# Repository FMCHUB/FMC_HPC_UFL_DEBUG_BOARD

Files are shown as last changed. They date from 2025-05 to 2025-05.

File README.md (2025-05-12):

# FMC HPC U.FL Debug Board

A flexible breakout and debugging platform for High-Pin Count (HPC) FPGA Mezzanine Cards (FMC).  
Provides 156 signal connections via U.FL connectors, plus SMA and clamp probing options for signal measurement and testing.

📄 [**View Online Datasheet**](https://fmchub.github.io/projects/FMC_HPC_UFL_DEBUG_BOARD/Datasheet/FMC_HPC_UFL_DEBUG_BOARD_datasheet.html)

---

## 🔧 Features

- FMC HPC (VITA 57.1) compatible connector
- 156 signals broken out to U.FL connectors
- 68 LA (LPC) + 48 HA (HPC) + 8 CLK + 16 MGT differential signals
- 8 SMA connectors for high-speed probing
- 8 clamp connectors for low-speed oscilloscope probing
- Breakout of power pins, JTAG, and I²C (solderable pin headers)
- Stackable mechanical assembly with standoff mounting holes
- Open-source hardware

---

## 📚 Documentation

| Resource | Link |
|---|---|
| Datasheet | [HTML Version](https://fmchub.github.io/projects/FMC_HPC_UFL_DEBUG_BOARD/Datasheet/FMC_HPC_UFL_DEBUG_BOARD_datasheet.html) |
| Schematics | `/Drawings/T0017_HPC_UFL_DEBUG_BOARD_SCHEMATICS_2024_12_13_REV_A.pdf` |
| PCB Layers | `/Drawings/T0017_HPC_UFL_DEBUG_BOARD_LAYERS_2024_12_13_REV_A.pdf` |
| Mechanical Drawings | `/Drawings/T0017_HPC_UFL_DEBUG_BOARD_MECHANICAL_2024_12_13_REV_A.pdf` |
| Bill of Materials | `/FMC_HPC_UFL_DEBUG_BOM.csv` |
| Buy online | [IAM Electronic Webshop](https://www.iamelectronic.com/shop) |

---

## 🛠️ Assembly & Usage Notes

- Board exceeds FMC single-width outline → check mechanical clearance in your setup.
- Use spacers or standoffs to prevent mechanical stress.
- For JTAG/I²C use, solder standard 2.54 mm pin headers to breakout pads.
- SMA and U.FL connectors are intended for signal probing. Ensure correct termination.

---

## ⚠️ Warnings

- **Incorrect loopback or interconnects can damage connected hardware**. Always verify voltage levels and signal directions before making U.FL cable connections.
- Clamp connectors are suitable for low-frequency probing only.

---

## 💡 Applications

- FMC-based FPGA system debugging
- Signal probing (low-speed and high-speed)
- Loopback and interconnect test setups
- Educational FPGA labs and research environments

---

## 📘 License

This project is licensed under the **Do What The Fuck You Want To Public License (WTFPL)**.

> See [`LICENSE`](./COPYING) for full text.

---

## ✉️ Contact

Feedback and contributions welcome via GitHub Issues or Pull Requests.

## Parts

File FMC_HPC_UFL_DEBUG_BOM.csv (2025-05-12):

Designator | Comment | Manufacturer | Part | Quantity
J1, J2, J3, J4, J5, J6, J7, J8, J9, J10, J11, J12, J13, J14, J15, J16, J17, J18, J19, J20, J21, J22, J23, J24, J25, J26, J27, J28, J29, J30, J31, J32, J33, J34, J35, J36, J37, J38, J39, J40, J41, J42, J43, J44, J45, J46, J47, J48, J49, J50, J51, J52, J53, J54, J55, J56, J57, J58, J59, J60, J61, J62, J63, J64, J65, J66, J67, J68, J69, J70, J71, J72, J73, J74, J75, J76, J77, J78, J79, J80, J81, J82, J83, J84, J85, J86, J87, J88, J89, J90, J91, J92, J93, J94, J95, J96, J97, J98, J99, J100, J101, J102, J103, J104, J105, J106, J107, J108, J109, J110, J111, J112, J113, J114, J115, J116, J117, J118, J119, J120, J121, J122, J123, J124, J125, J126, J127, J128, J129, J130, J131, J132, J133, J134, J135, J136, J137, J138, J139, J140, J141, J142, J143, J144, J145, J146, J147, J148, J149, J150, J151, J152, J153, J154, J155, J156, JA1, JB1, JC1, JD1, JE1, JF1, JG1, JH1 | U.FL-R-SMT-1(01) | Hirose Electric | U.FL-R-SMT-1(01) | 164
TPA1, TPB1, TPC1, TPD1, TPE1, TPF1, TPG2, TPH1 | Testpoint | Keystone Electronics | 5095 | 8
JA2, JB2, JC2, JD2, JE2, JF2, JG2, JH2 | SMA-J-P-H-ST-EM1 | Samtec | SMA-J-P-H-ST-EM1 | 8
P1 | MC-HPC-10 | Samtec | ASP-134488-01 | 1
P2 | CC-HPC-10 | Samtec | ASP-134486-01 | 1

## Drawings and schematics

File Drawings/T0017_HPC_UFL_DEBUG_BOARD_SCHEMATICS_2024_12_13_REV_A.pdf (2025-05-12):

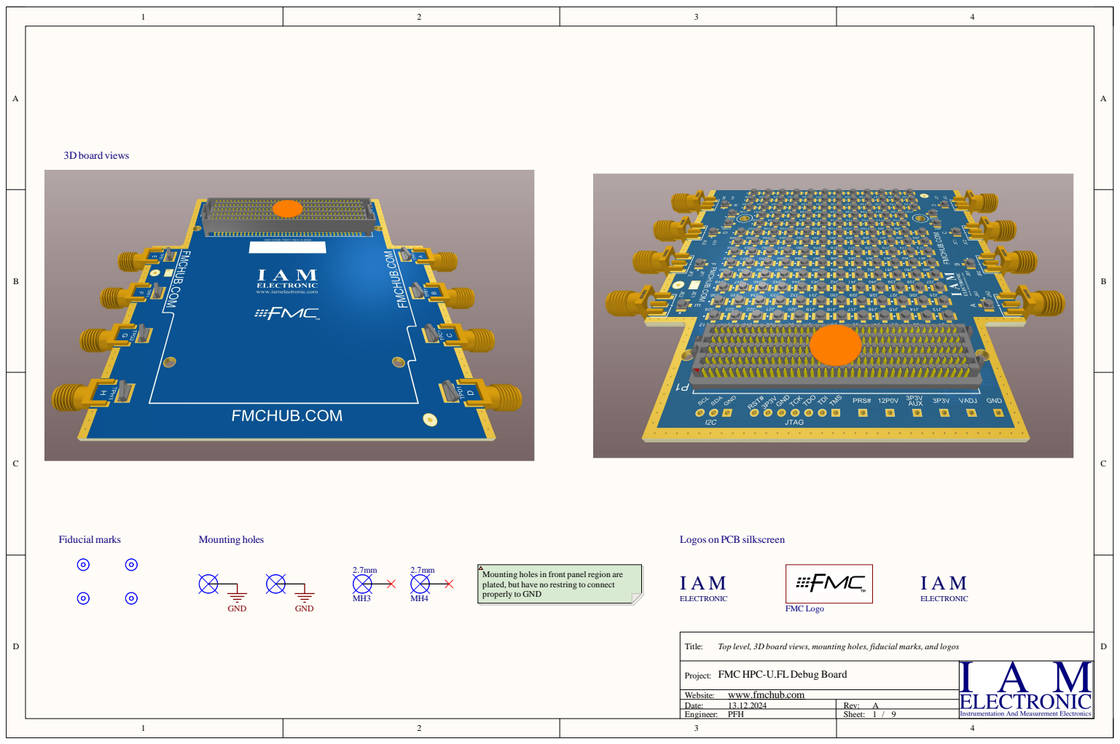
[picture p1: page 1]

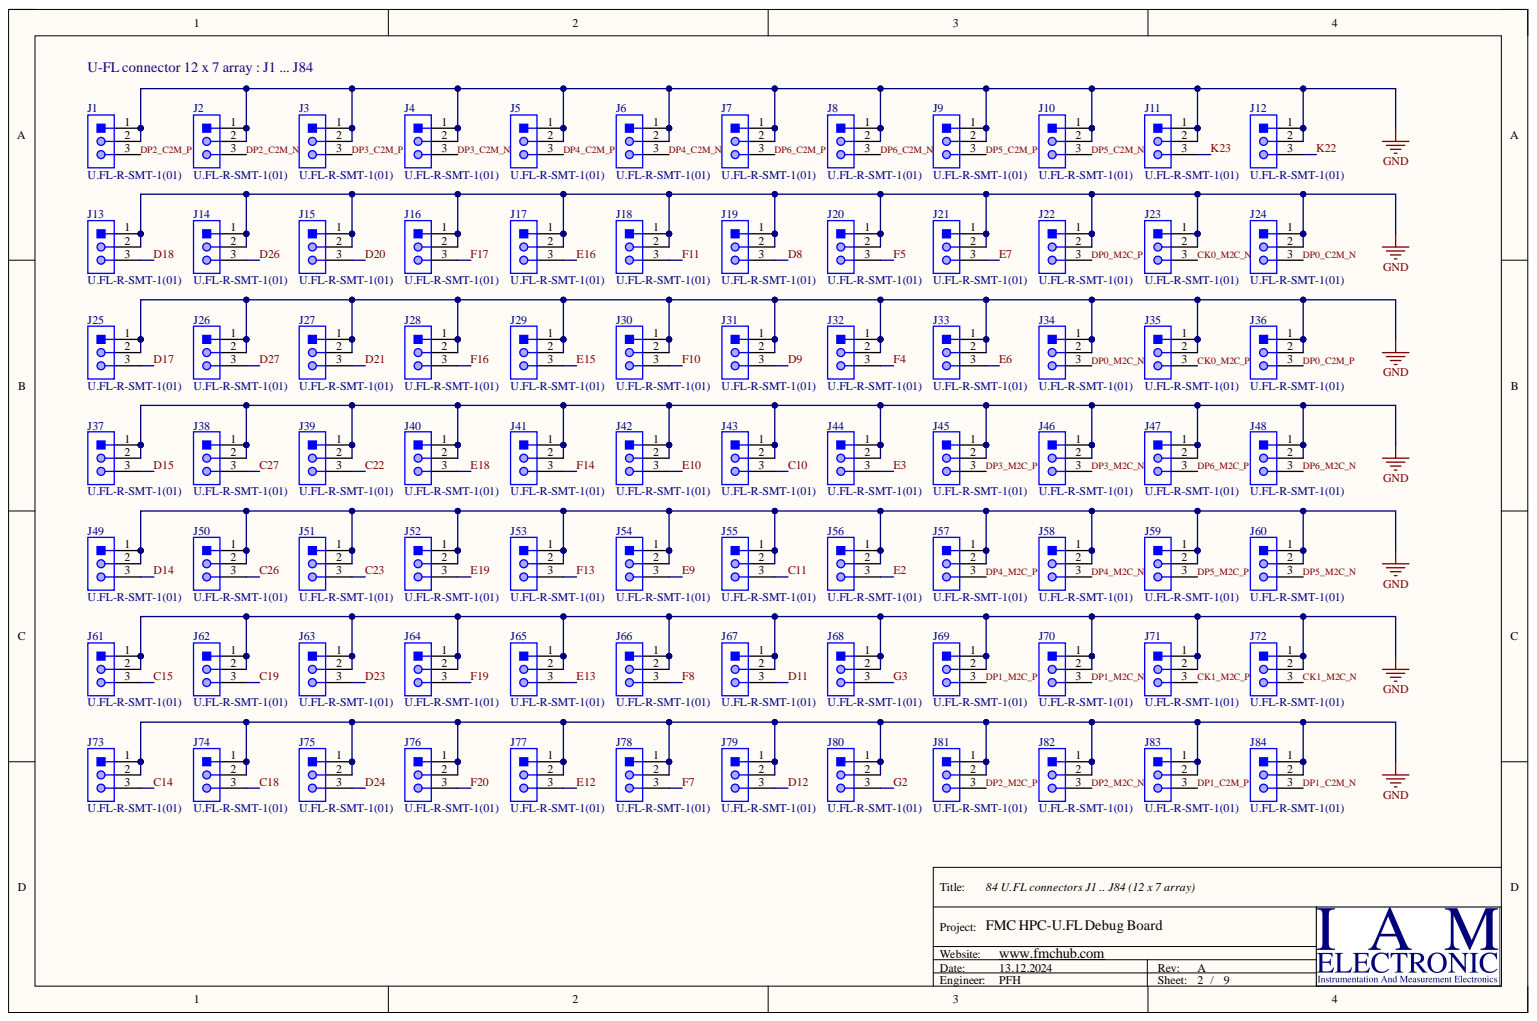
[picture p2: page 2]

FMC HPC-U.FL Debug Board

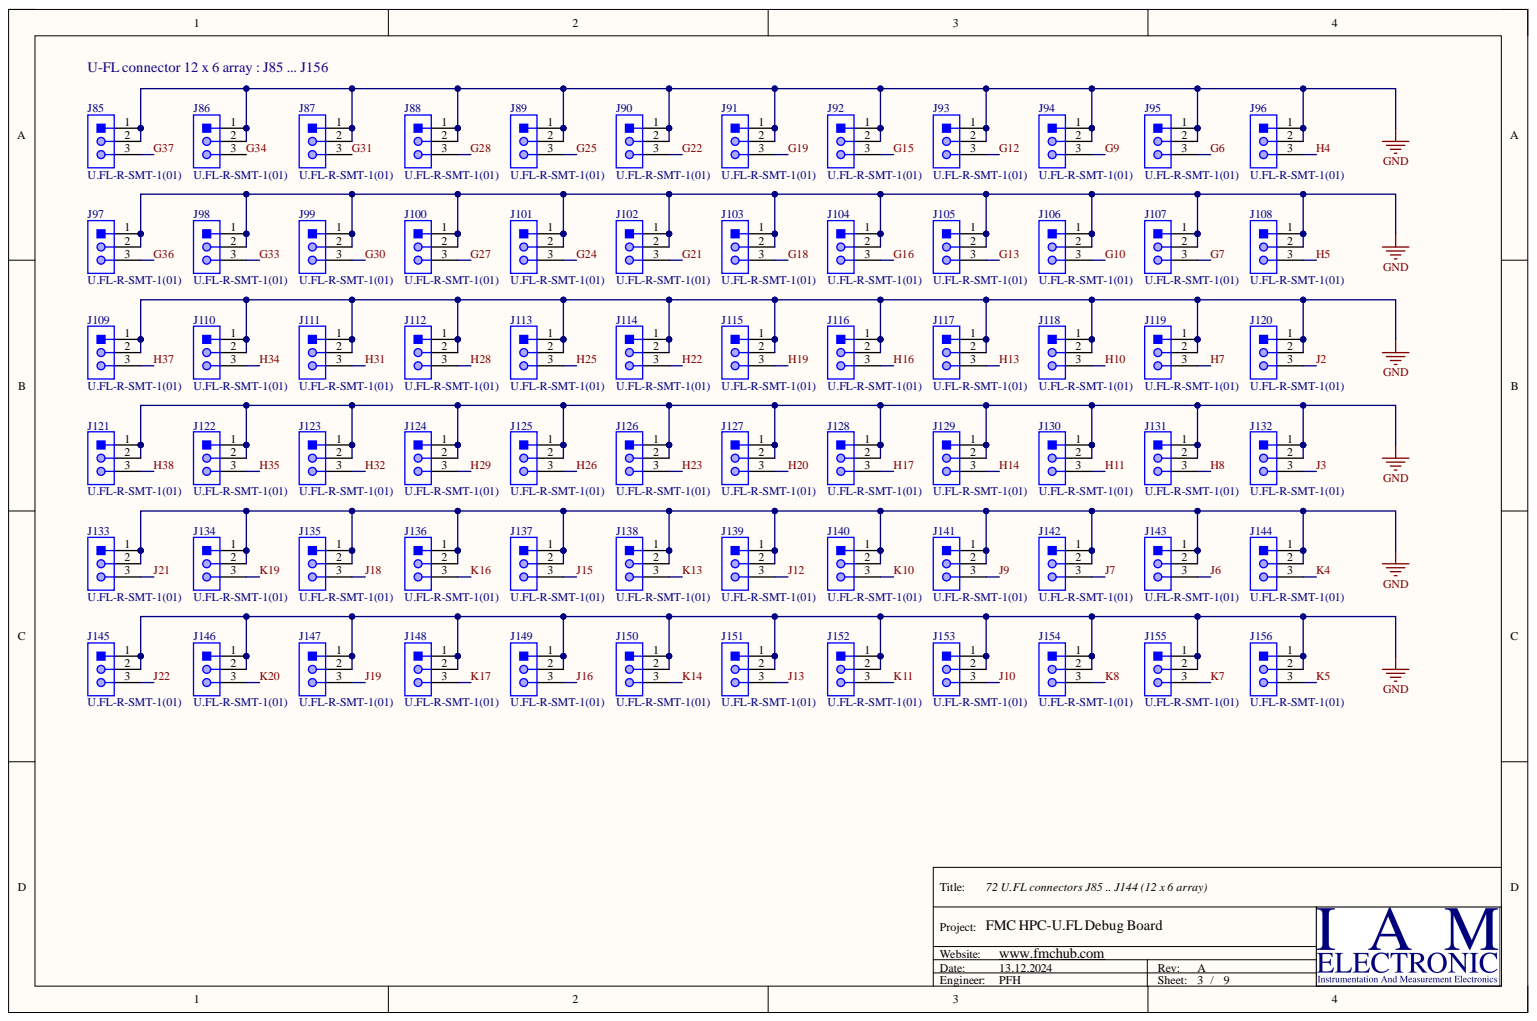
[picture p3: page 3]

FMC HPC-U.FL Debug Board

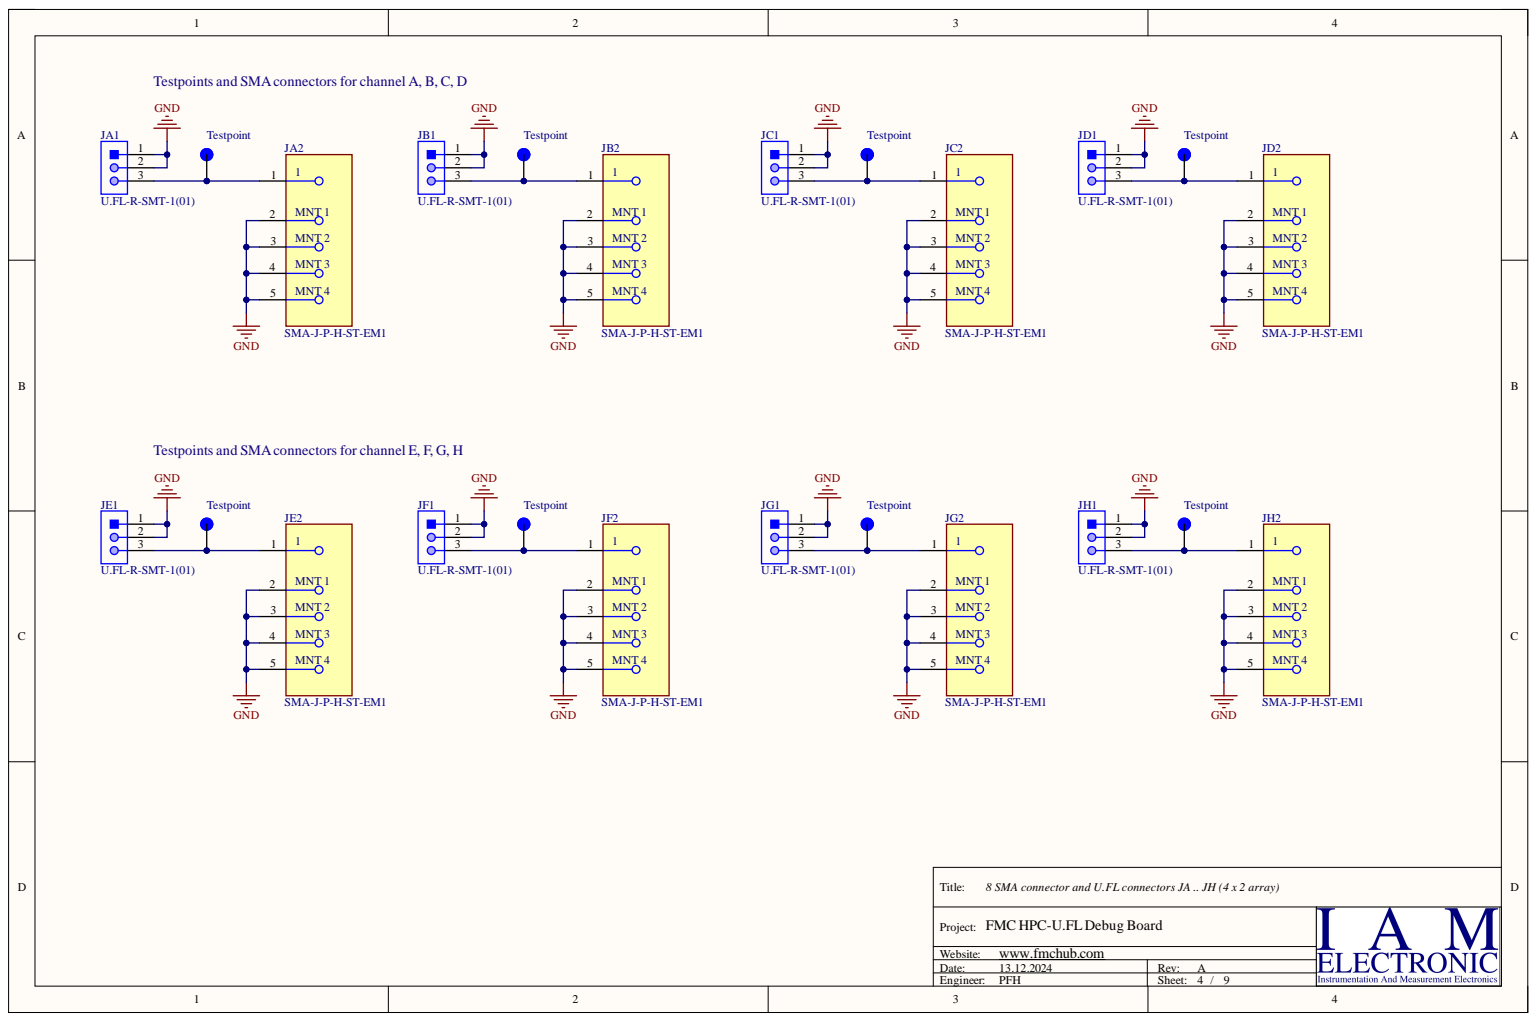
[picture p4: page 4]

Testpoints and SMAconnectors for channel A, B, C, D

Testpoints and SMAconnectors for channel E, F, G, H

8 SMA connector and U.FL connectors JA .. JH (4 x 2 array)

FMC HPC-U.FL Debug Board

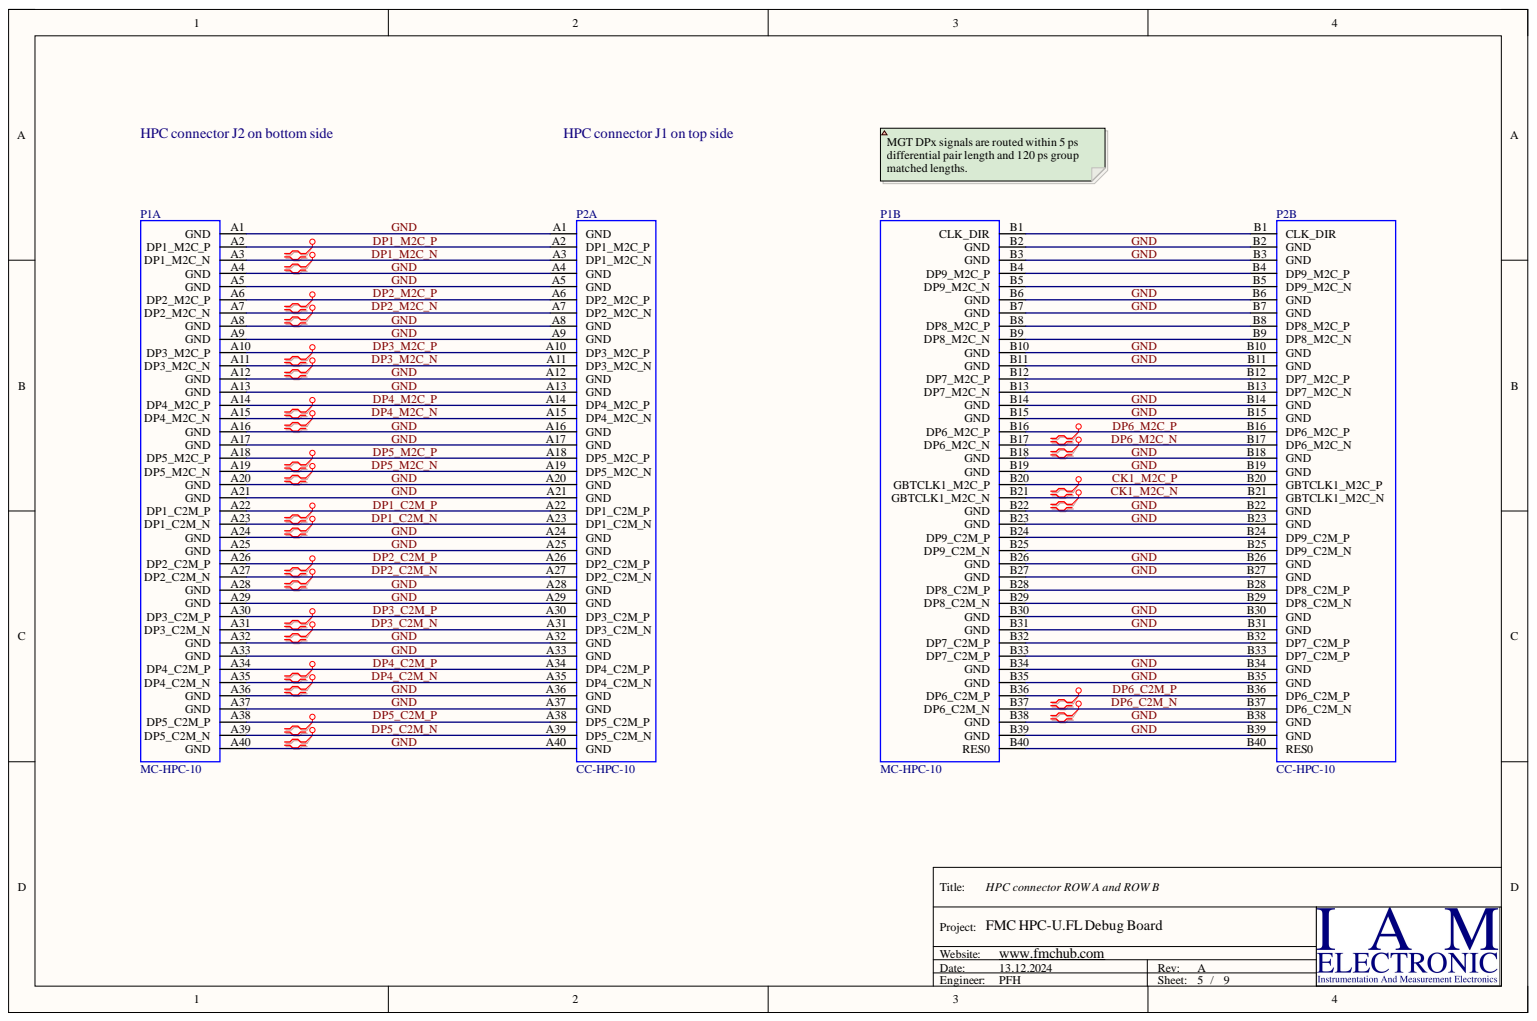
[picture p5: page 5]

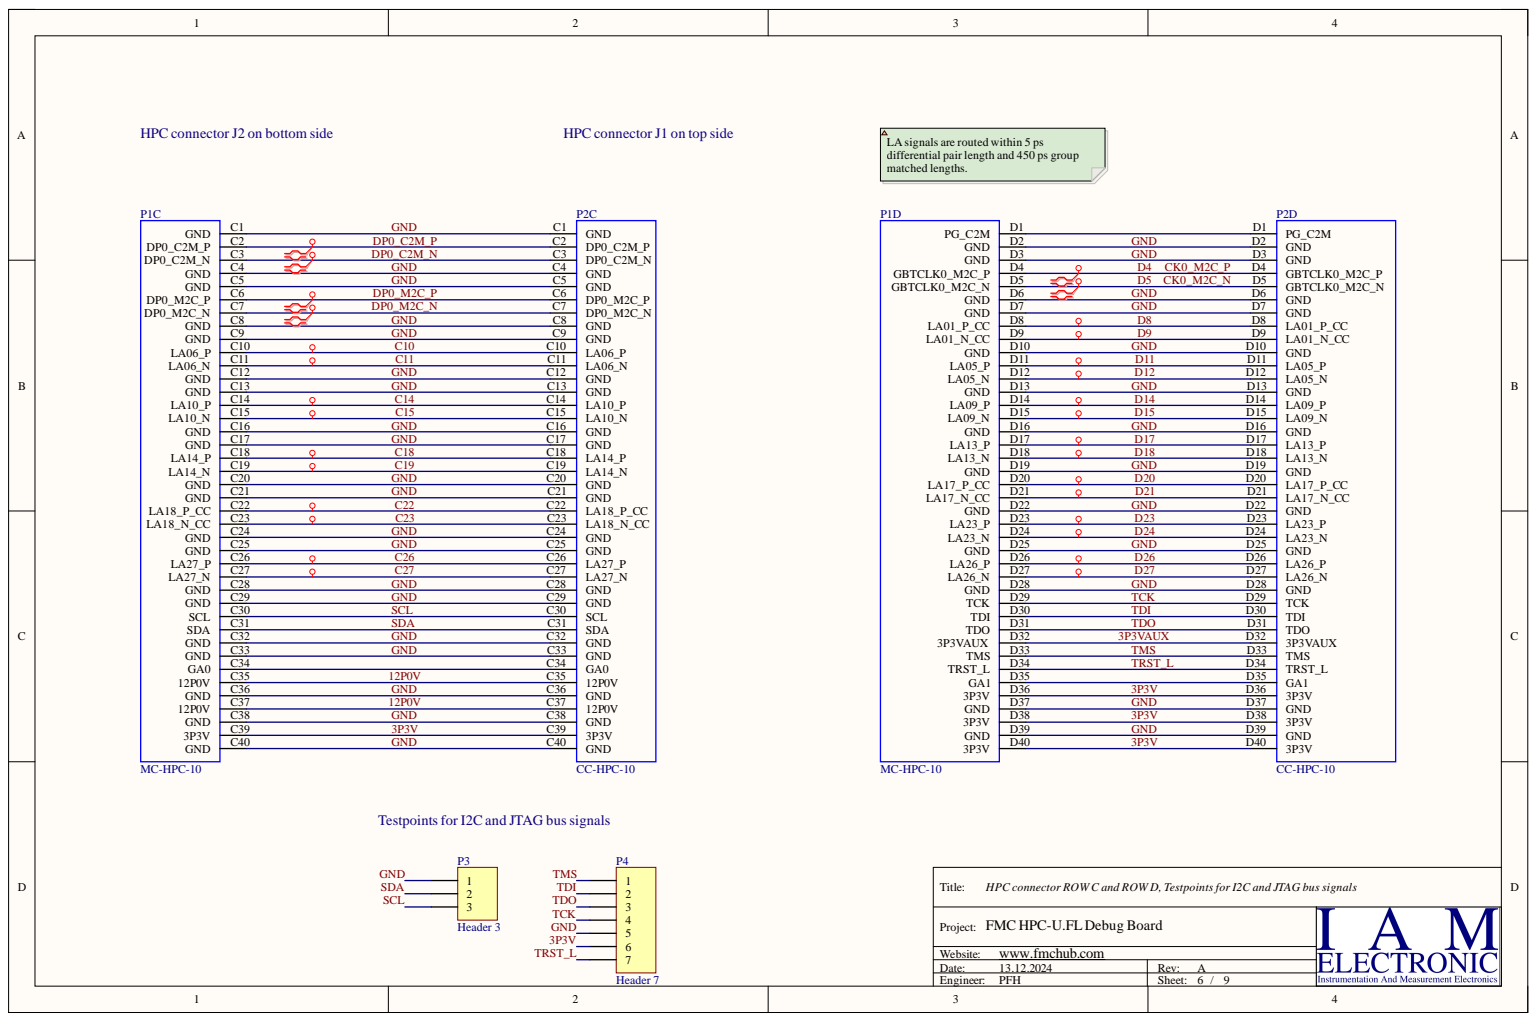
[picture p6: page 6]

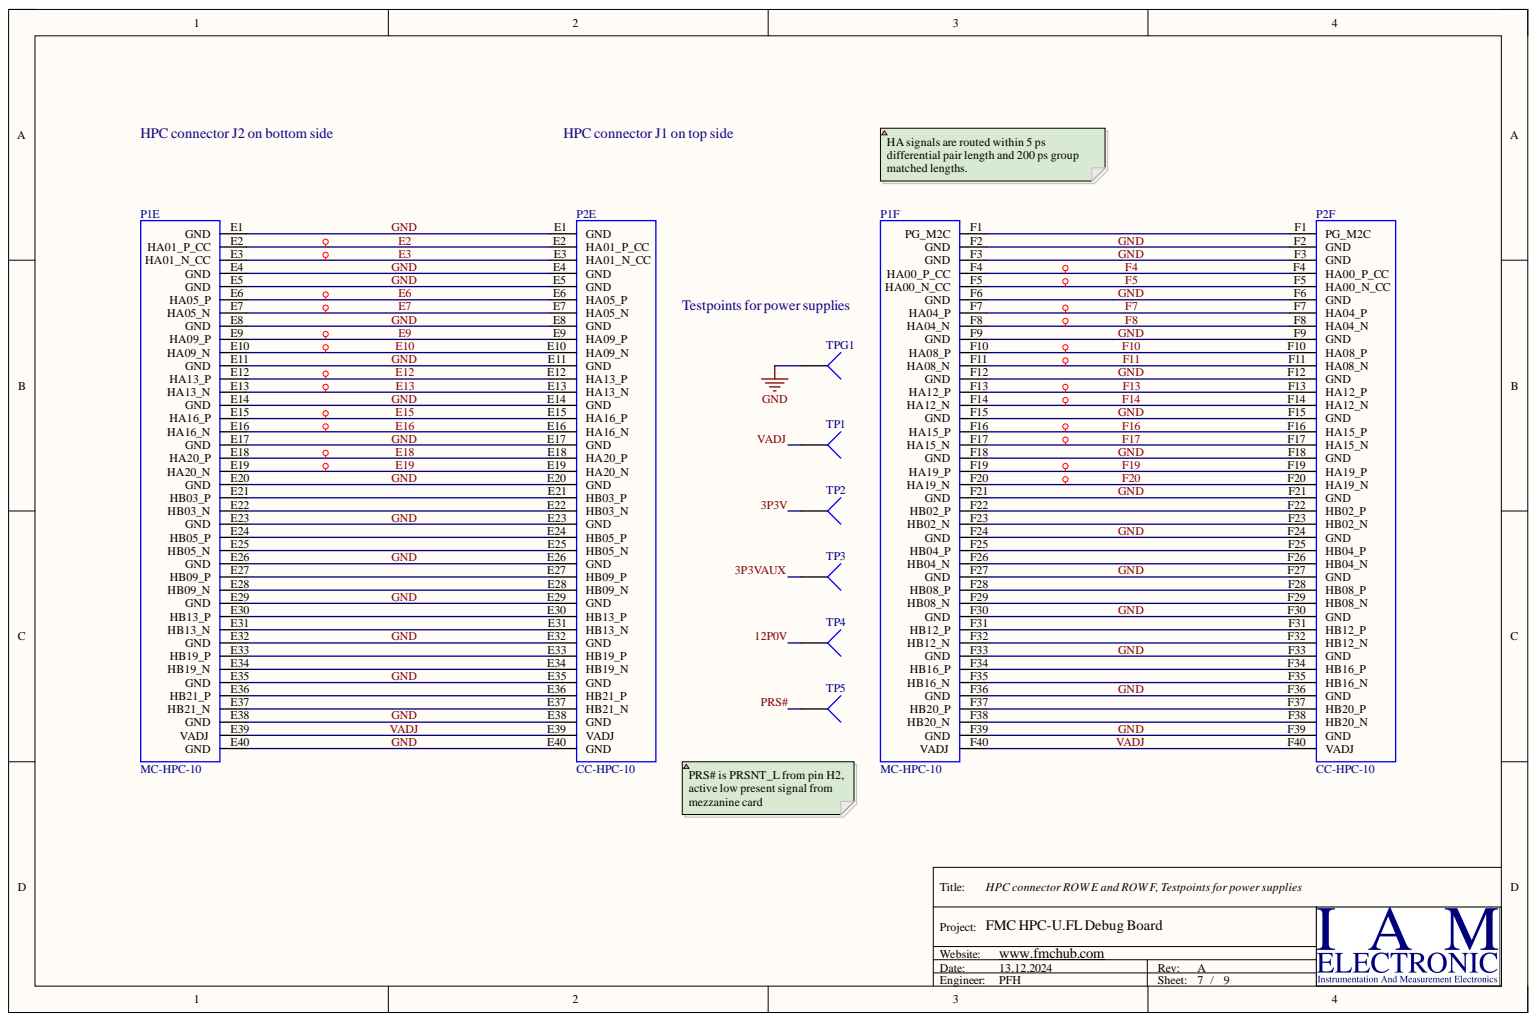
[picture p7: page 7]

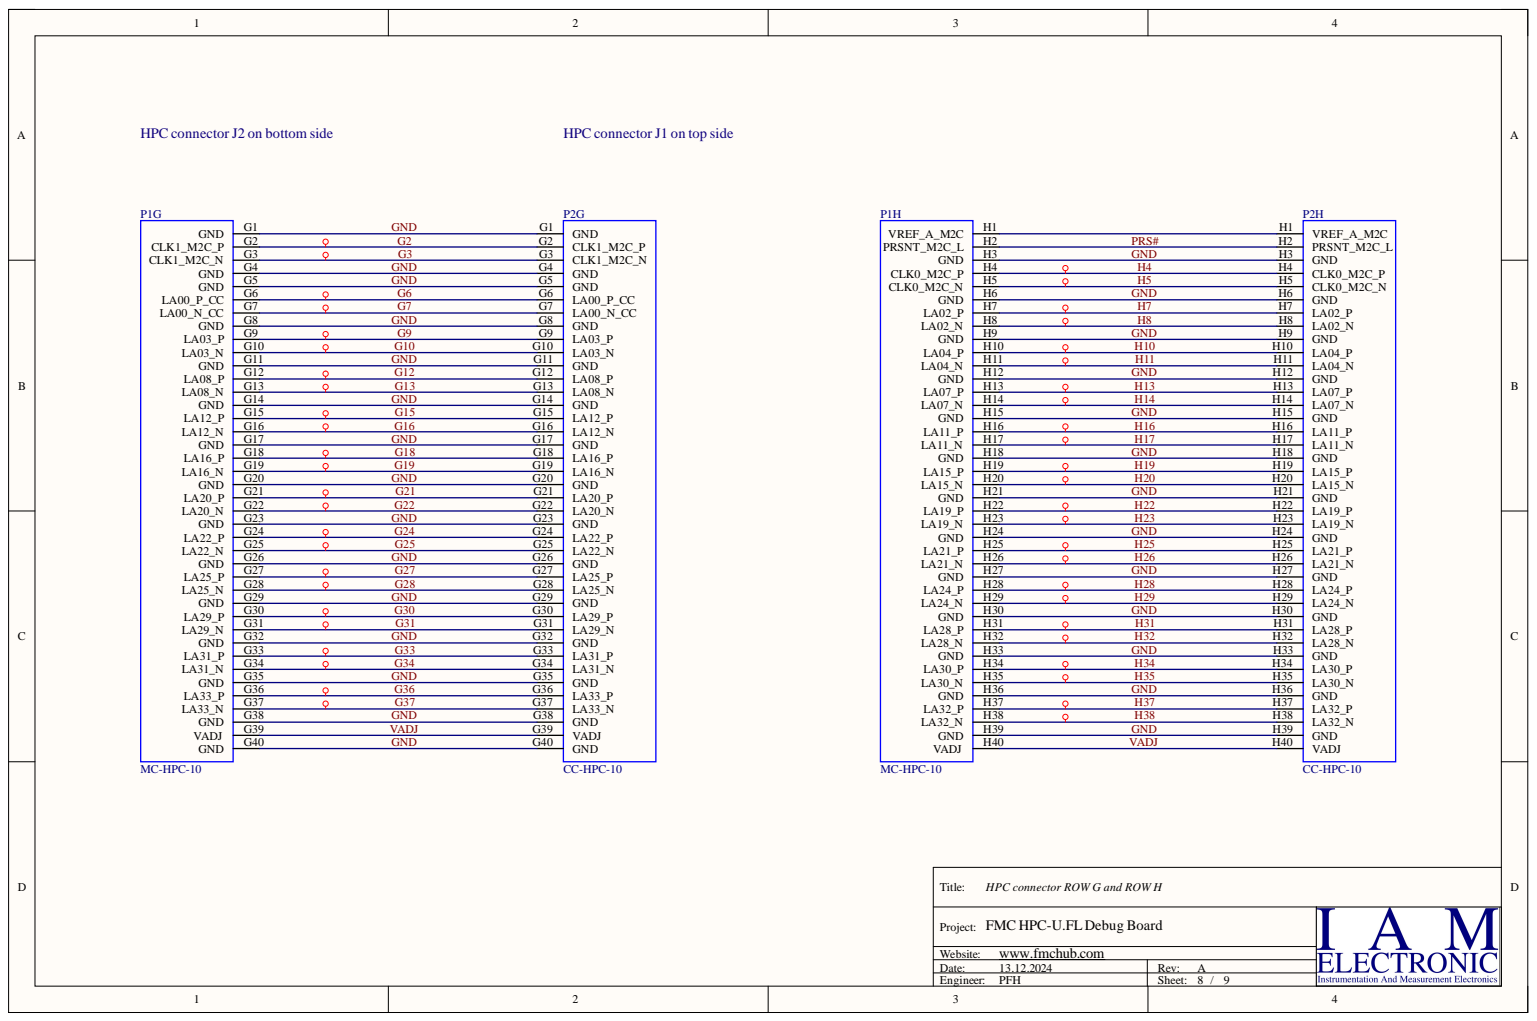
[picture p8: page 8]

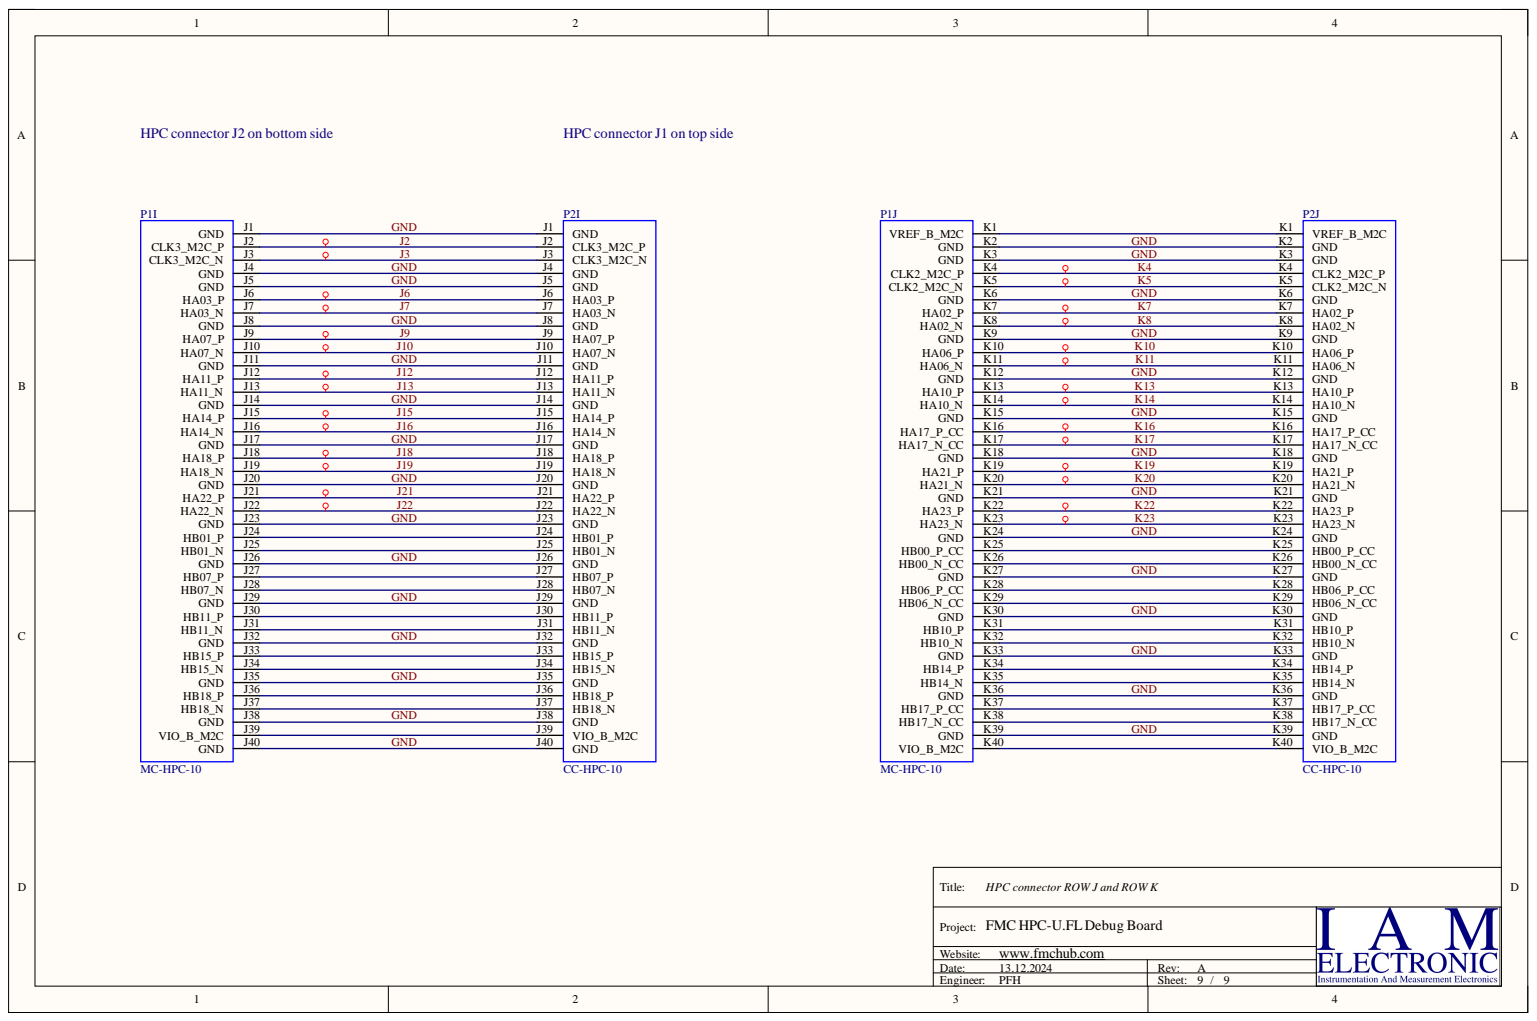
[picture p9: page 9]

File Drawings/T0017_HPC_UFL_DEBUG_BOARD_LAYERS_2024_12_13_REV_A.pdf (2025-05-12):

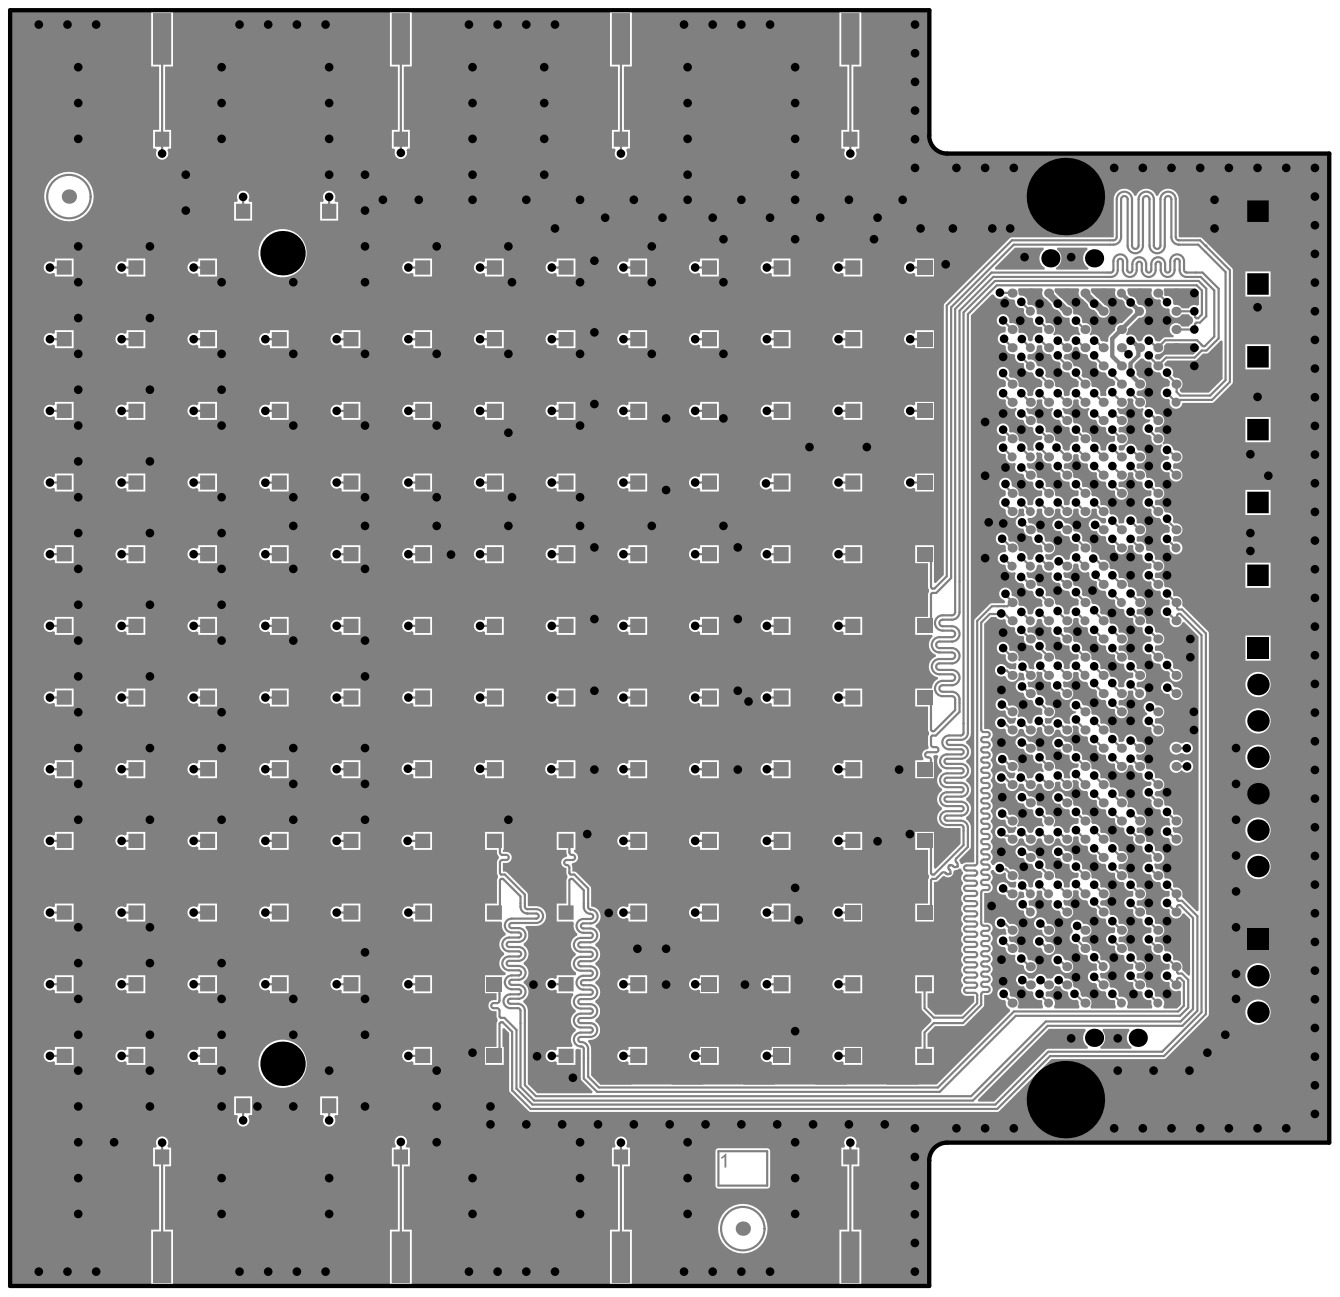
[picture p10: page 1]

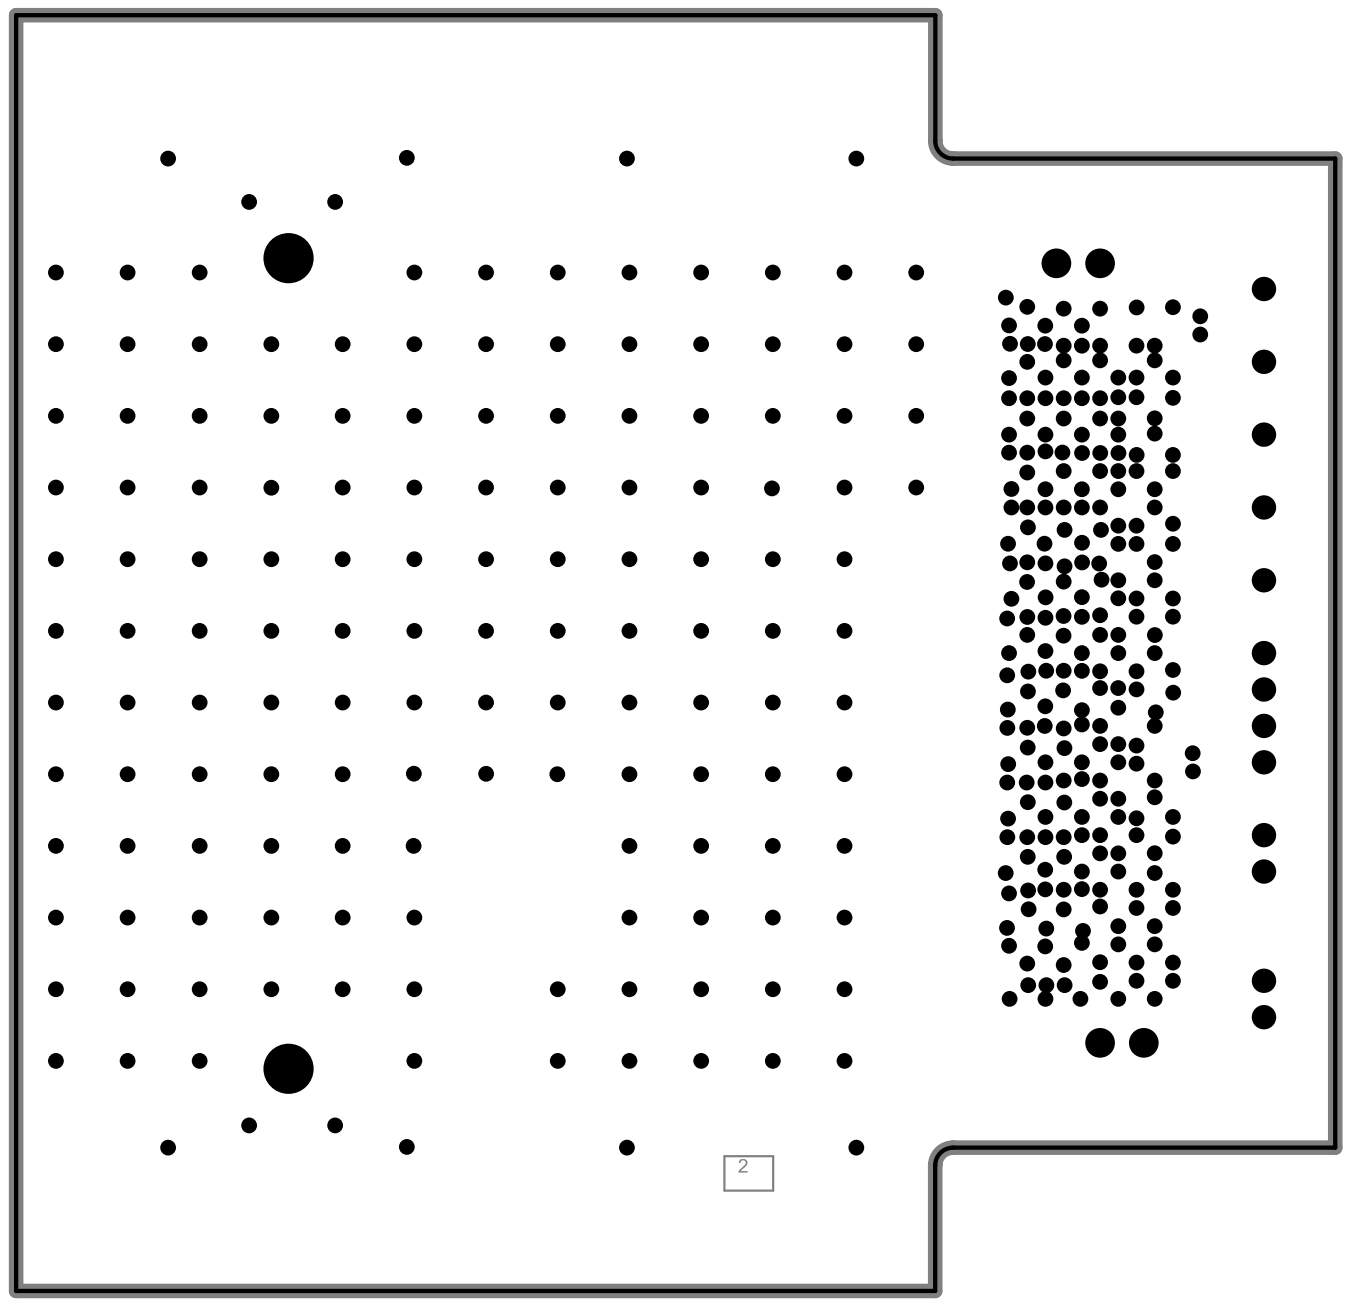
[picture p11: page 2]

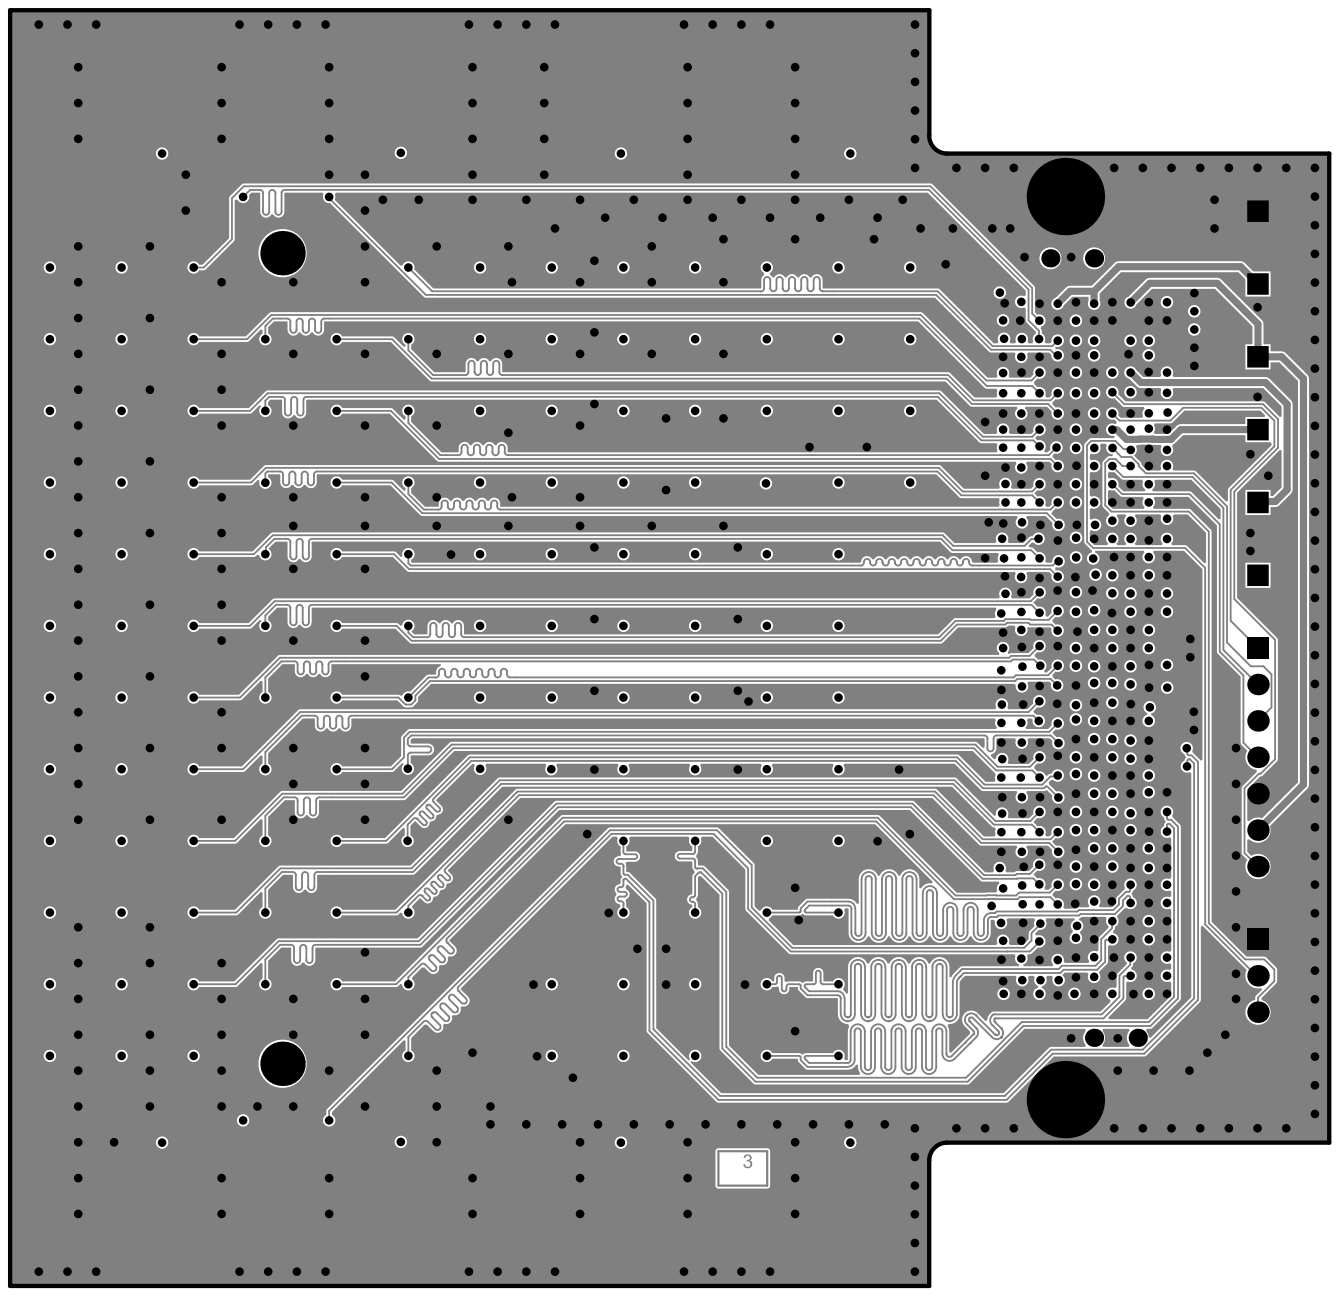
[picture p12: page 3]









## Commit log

2025-05-12 initial release
    [FMC_HPC_UFL_DEBUG_HPC_AB.SchDoc, FMC_HPC_UFL_DEBUG_HPC_CD.SchDoc, FMC_HPC_UFL_DEBUG_HPC_EF.SchDoc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]
2025-05-12 add: BOM info, buying link
    [FMC_HPC_UFL_DEBUG_BOM.csv]
